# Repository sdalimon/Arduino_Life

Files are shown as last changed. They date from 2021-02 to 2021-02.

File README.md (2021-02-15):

# Arduino_Life
A little Arduino compatible LED art project

It consists of a two board stack.  
The lower board has an ATMega328 loaded with the Arduino bootloader.  It also has the row drivers for the LED array.
The upper board is an 8x8 array of LEDs in a standard row/column arrangement.

This was called Arduino Life because I planned to do Game of Life on it, but found a nicer looking pattern that doesn't need to worry about geting stuck.

The software is in the LED_Worm which implements a dot bouncing around the LEDs toggleing the current LED.  It randomly turns to give a less repeatitive pattern.  The software is written using the Arduino IDE.  

To program, use a USB to TTL (or other TTL UART) interface.  Press the reset button after clicking Program in the Arduino IDE (or install the chip in an Arduino Uno and program there).

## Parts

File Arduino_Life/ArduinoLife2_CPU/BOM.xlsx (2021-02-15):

Ref | Qnty | Value | Cmp name | Footprint | Description | Vendor
C1, C2, C3, | 3 | 100n | C | Capacitor_THT:C_Disc_D5.0mm_W2.5mm_P5.00mm | Unpolarized capacitor | RDER71H104K0P1H03B
C4, C5, | 2 | 22p | C | Capacitor_THT:C_Disc_D5.0mm_W2.5mm_P5.00mm | Unpolarized capacitor | RDE5C2A220J0S1H03A
C6, | 1 | 10u | CP1 | Capacitor_THT:CP_Radial_D6.3mm_P2.50mm | Polarised capacitor | 860130673001
J1, | 1 | Conn_01x09 | Conn_01x09 | Connector_PinSocket_2.54mm:PinSocket_1x09_P2.54mm_Vertical | Generic connector, single row, 01x09, script generated (kicad-library-utils/schlib/autogen/connector/) | PPPC091LFBN-RC
J2, J3, J4, | 3 | Conn_01x08 | Conn_01x08 | Connector_PinSocket_2.54mm:PinSocket_1x08_P2.54mm_Vertical | Generic connector, single row, 01x08, script generated (kicad-library-utils/schlib/autogen/connector/) | PPPC081LFBN-RC
J5, | 1 | Conn_01x03 | Conn_01x03 | Connector_PinHeader_2.54mm:PinHeader_1x03_P2.54mm_Horizontal | Generic connector, single row, 01x03, script generated (kicad-library-utils/schlib/autogen/connector/) | PH1RB-03-UA
J6, | 1 | KUSBX-SL-CS1N14-B | KUSBX-SL-CS1N14-B | ArduinoLife2 - CPU:KUSBX-SL-CS1N14-B |  | KUSBX-SL-CS1N14-B
Q1, Q2, Q3, Q4, Q5, Q6, Q7, Q8, | 8 | 2N3904 | 2N3904 | Package_TO_SOT_THT:TO-92_Inline | 0.2A Ic, 40V Vce, Small Signal NPN Transistor, TO-92 | 2N3904BU
R1, R2, R3, R4, R5, R6, R7, R8, R9, R10, R11, R12, R13, R14, R15, R16, | 16 | 560 | R | Resistor_THT:R_Axial_DIN0207_L6.3mm_D2.5mm_P10.16mm_Horizontal | Resistor | CF14JT560R
R17, R18, | 2 | 5k1 | R | Resistor_THT:R_Axial_DIN0207_L6.3mm_D2.5mm_P10.16mm_Horizontal | Resistor | RNMF14FTC5K10
R20, | 1 | 10k | R | Resistor_THT:R_Axial_DIN0207_L6.3mm_D2.5mm_P10.16mm_Horizontal | Resistor | CF14JT10K0
SW1, | 1 | SW_Push | SW_Push | Button_Switch_THT:SW_PUSH_6mm | Push button switch, generic, two pins | 1825910-6
U1, | 1 | ATmega328P-PU | ATmega328P-PU | Package_DIP:DIP-28_W7.62mm | PDIP28 Narrow, 32k Flash, 2kB SRAM, 1kB EEPROM | ATMEGA328P-PU
Y1, | 1 | 16M | Crystal | Crystal:HC-46X | Two pin crystal | ECS-160-20-46X
D1, D2, D3, D4, D5, D6, D7, D8, D9, D10, D11, D12, D13, D14, D15, D16, D17, D18, D19, D20, D21, D22, D23, D24, D25, D26, D27, D28, D29, D30, D31, D32, D33, D34, D35, D36, D37, D38, D39, D40, D41, D42, D43, D44, D45, D46, D47, D48, D49, D50, D51, D52, D53, D54, D55, D56, D57, D58, D59, D60, D61, D62, D63, D64, | 64 | LED | LED | LED_THT:LED_D5.0mm | LED generic | 151051RS11000
J1, | 1 | Conn_01x09 | Conn_01x09 | Connector_PinHeader_2.54mm:PinHeader_1x09_P2.54mm_Vertical | Generic connector, single row, 01x09, script generated (kicad-library-utils/schlib/autogen/connector/) | PRPC009SAAN-RC
J2, J3, J4, | 3 | Conn_01x08 | Conn_01x08 | Connector_PinHeader_2.54mm:PinHeader_1x08_P2.54mm_Vertical | Generic connector, single row, 01x08, script generated (kicad-library-utils/schlib/autogen/connector/) | PH1-08-UA

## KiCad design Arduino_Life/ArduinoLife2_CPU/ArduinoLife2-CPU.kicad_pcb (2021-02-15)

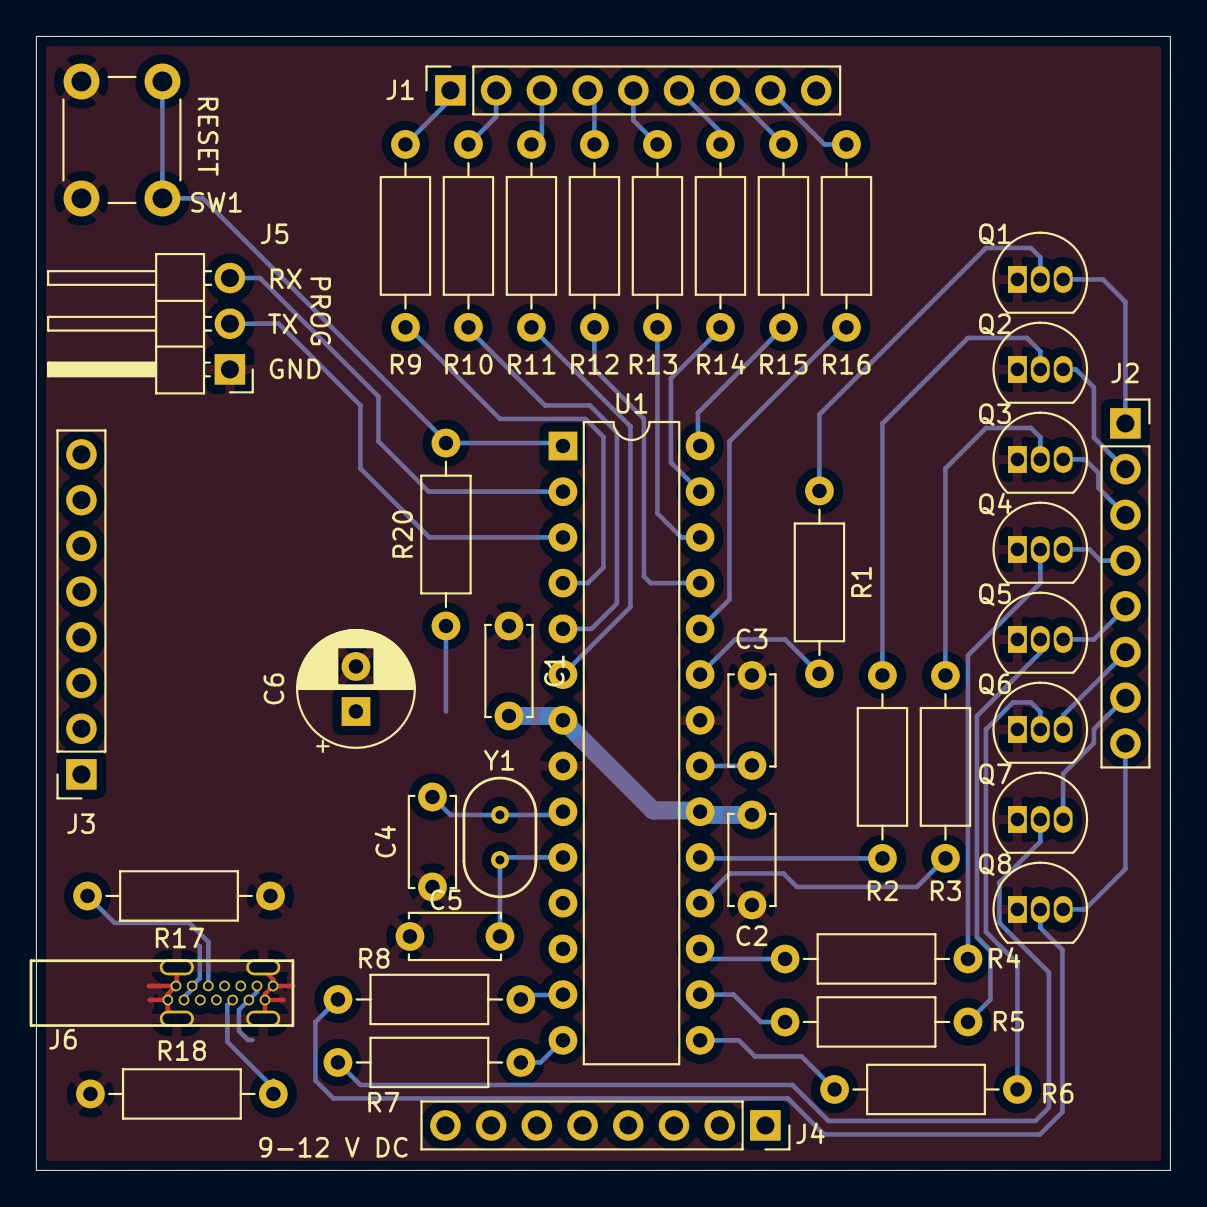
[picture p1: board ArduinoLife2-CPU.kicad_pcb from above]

Board: 2 copper layers, 63.0 x 63.0 mm, 42 parts (0 on the bottom side), 50 nets.

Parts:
C1, C2, C3: 100n; C_Disc_D5.0mm_W2.5mm_P5.00mm
C4, C5: 22p; C_Disc_D5.0mm_W2.5mm_P5.00mm
C6: 10u; CP_Radial_D6.3mm_P2.50mm
J1: Conn_01x09; PinSocket_1x09_P2.54mm_Vertical
J2, J3, J4: Conn_01x08; PinSocket_1x08_P2.54mm_Vertical
J5: Conn_01x03; PinHeader_1x03_P2.54mm_Horizontal
J6: KUSBX-SL-CS1N14-B
Q1, Q2, Q3, Q4, Q5, Q6, Q7, Q8: 2N3904; TO-92_Inline
R1, R2, R3, R4, R5, R6, R7, R8, R9, R10, R11, R12, R13, R14, R15, R16: 560; R_Axial_DIN0207_L6.3mm_D2.5mm_P10.16mm_Horizontal
R17, R18: 5k1; R_Axial_DIN0207_L6.3mm_D2.5mm_P10.16mm_Horizontal
R20: 10k; R_Axial_DIN0207_L6.3mm_D2.5mm_P10.16mm_Horizontal
SW1: SW_Push; SW_PUSH_6mm
U1: ATmega328P-PU; DIP-28_W7.62mm
Y1: 16M; HC-46X

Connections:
/C0: J1.1, R9.1
/C1: J1.2, R10.1
/C2: J1.3, R11.1
/C3: J1.4, R12.1
/C4: J1.5, R13.1
/C5: J1.6, R14.1
/C6: J1.7, R15.1
/C7: J1.8, R16.1
/CC1: J6.A5, R17.2
/CC2: J6.B5, R18.2
/R0: J2.1, Q1.3
/R1: J2.2, Q2.3
/R2: J2.3, Q3.3
/R3: J2.4, Q4.3
/R4: J2.5, Q5.3
/R5: J2.6, Q6.3
/R6: J2.7, Q7.3
/R7: J2.8, Q8.3
/RX: J5.3, U1.2
/TX: J5.2, U1.3
/UC_C0: R9.2, U1.4
/UC_C1: R10.2, U1.5
/UC_C2: R11.2, U1.6
/UC_C3: R12.2, U1.25
/UC_C4: R13.2, U1.26
/UC_C5: R14.2, U1.27
/UC_C6: R15.2, U1.28
/UC_C7: R16.2, U1.24
/UC_R0: R1.2, U1.23
/UC_R1: R2.2, U1.19
/UC_R2: R3.2, U1.18
/UC_R3: R4.2, U1.17
/UC_R4: R5.2, U1.16
/UC_R5: R6.2, U1.15
/UC_R6: R7.2, U1.14
/UC_R7: R8.2, U1.13
/X1: C4.2, U1.9, Y1.1
/X2: C5.2, U1.10, Y1.2
/~RESET: R20.2, SW1.1, U1.1
GND: C1.1, C2.1, C3.1, C4.1, C5.1, C6.2, J5.1, J6.A1, J6.A12, J6.B1, J6.B12, J6.CASE, Q1.1, Q2.1, Q3.1, Q4.1, Q5.1, Q6.1, Q7.1, Q8.1, R17.1, R18.1, SW1.2, U1.8, U1.22
unnamed: C3.2, U1.21
unnamed: Q1.2, R1.1
unnamed: Q2.2, R2.1
unnamed: Q3.2, R3.1
unnamed: Q4.2, R4.1
unnamed: Q5.2, R5.1
unnamed: Q6.2, R6.1
unnamed: Q7.2, R7.1
unnamed: Q8.2, R8.1
VCC: C1.2, C2.2, C6.1, J6.A4, J6.A9, J6.B4, J6.B9, R20.1, U1.7, U1.20

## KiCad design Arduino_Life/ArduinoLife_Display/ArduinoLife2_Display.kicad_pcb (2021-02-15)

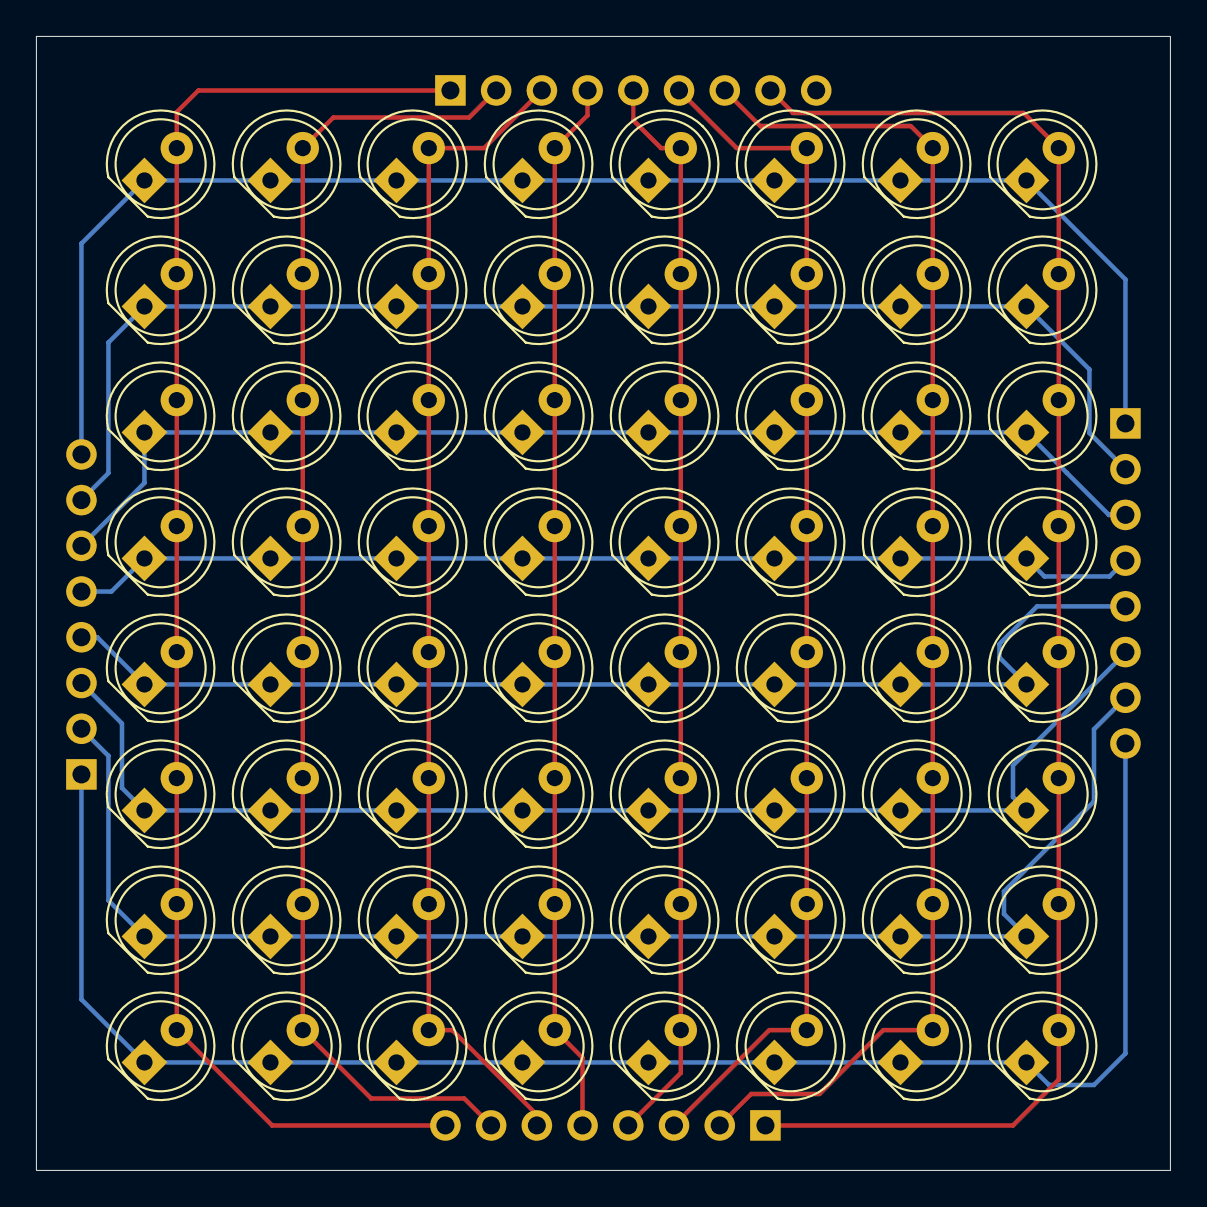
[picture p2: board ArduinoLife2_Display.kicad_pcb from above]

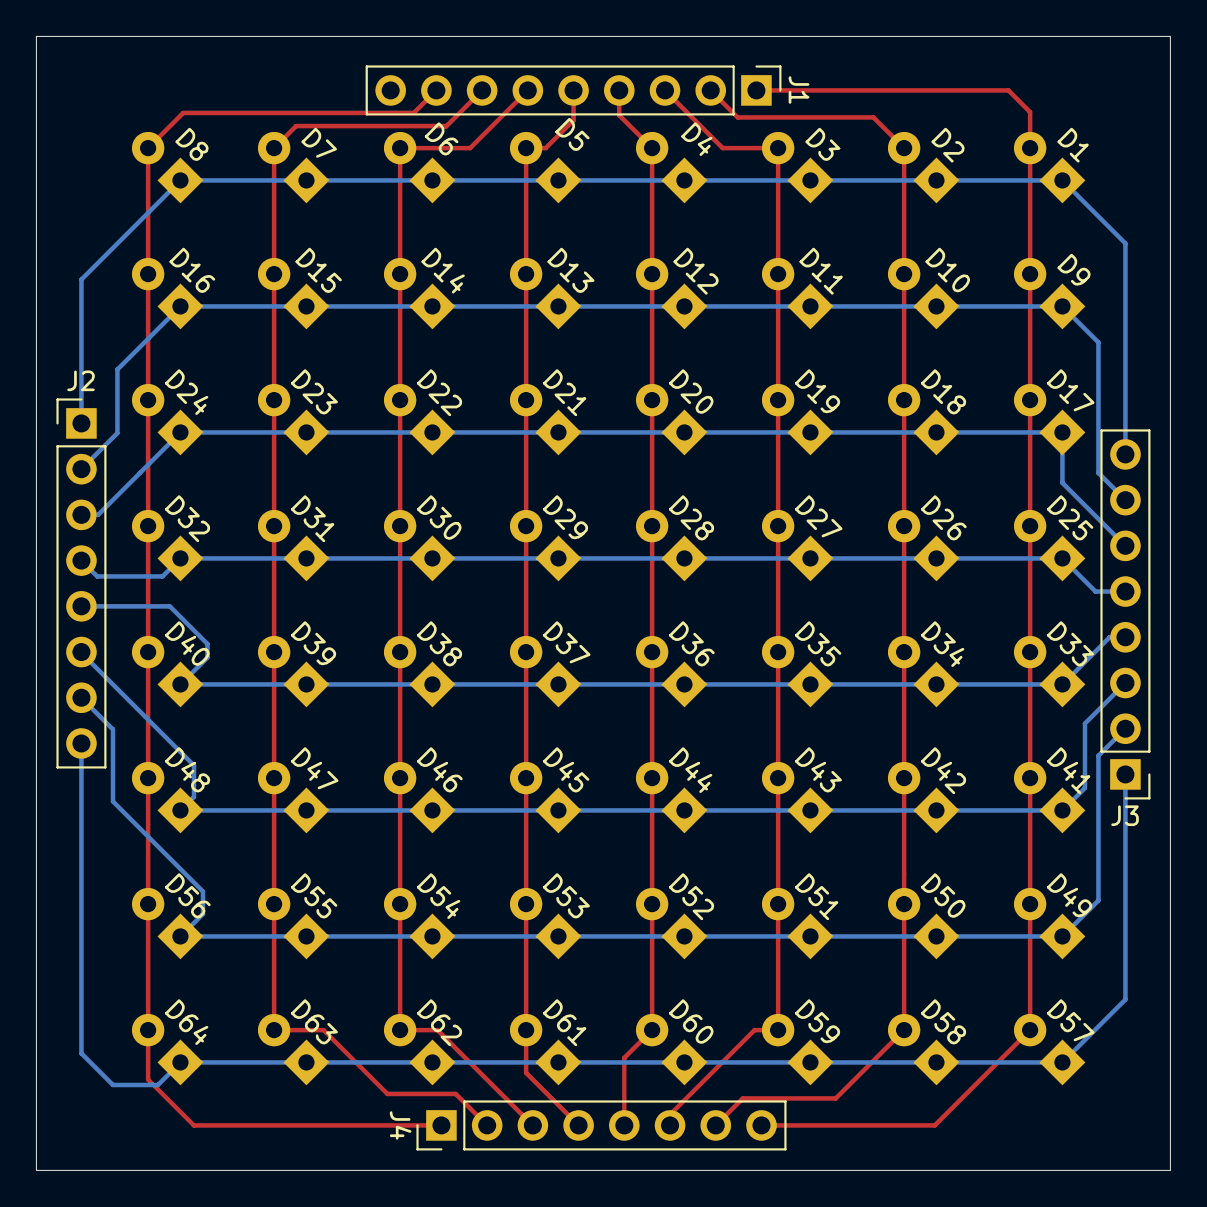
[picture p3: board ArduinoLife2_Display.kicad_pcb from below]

Board: 2 copper layers, 63.0 x 63.0 mm, 68 parts (4 on the bottom side), 16 nets.

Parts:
D1, D2, D3, D4, D5, D6, D7, D8, D9, D10, D11, D12, D13, D14, D15, D16, D17, D18, D19, D20, D21, D22, D23, D24, D25, D26, D27, D28, D29, D30, D31, D32, D33, D34, D35, D36, D37, D38, D39, D40, D41, D42, D43, D44, D45, D46, D47, D48, D49, D50, D51, D52, D53, D54, D55, D56, D57, D58, D59, D60, D61, D62, D63, D64: LED; LED_D5.0mm
J1: Conn_01x09; PinHeader_1x09_P2.54mm_Vertical
J2, J3, J4: Conn_01x08; PinHeader_1x08_P2.54mm_Vertical

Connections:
/C0: D1.2, D9.2, D17.2, D25.2, D33.2, D41.2, D49.2, D57.2, J1.1, J4.8
/C1: D2.2, D10.2, D18.2, D26.2, D34.2, D42.2, D50.2, D58.2, J1.2, J4.7
/C2: D3.2, D11.2, D19.2, D27.2, D35.2, D43.2, D51.2, D59.2, J1.3, J4.6
/C3: D4.2, D12.2, D20.2, D28.2, D36.2, D44.2, D52.2, D60.2, J1.4, J4.5
/C4: D5.2, D13.2, D21.2, D29.2, D37.2, D45.2, D53.2, D61.2, J1.5, J4.4
/C5: D6.2, D14.2, D22.2, D30.2, D38.2, D46.2, D54.2, D62.2, J1.6, J4.3
/C6: D7.2, D15.2, D23.2, D31.2, D39.2, D47.2, D55.2, D63.2, J1.7, J4.2
/C7: D8.2, D16.2, D24.2, D32.2, D40.2, D48.2, D56.2, D64.2, J1.8, J4.1
/R0: D1.1, D2.1, D3.1, D4.1, D5.1, D6.1, D7.1, D8.1, J2.1, J3.8
/R1: D9.1, D10.1, D11.1, D12.1, D13.1, D14.1, D15.1, D16.1, J2.2, J3.7
/R2: D17.1, D18.1, D19.1, D20.1, D21.1, D22.1, D23.1, D24.1, J2.3, J3.6
/R3: D25.1, D26.1, D27.1, D28.1, D29.1, D30.1, D31.1, D32.1, J2.4, J3.5
/R4: D33.1, D34.1, D35.1, D36.1, D37.1, D38.1, D39.1, D40.1, J2.5, J3.4
/R5: D41.1, D42.1, D43.1, D44.1, D45.1, D46.1, D47.1, D48.1, J2.6, J3.3
/R6: D49.1, D50.1, D51.1, D52.1, D53.1, D54.1, D55.1, D56.1, J2.7, J3.2
/R7: D57.1, D58.1, D59.1, D60.1, D61.1, D62.1, D63.1, D64.1, J2.8, J3.1

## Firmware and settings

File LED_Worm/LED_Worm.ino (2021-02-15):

// Randomly toggle LEDs on an 8x8 array

#include <MsTimer2.h>

const int PIN_ROW[8] = {A0, 13, 12, 11, 10, 9, 8, 7};
const int PIN_COL[8] = {2, 3, 4, A2, A3, A4, A5, A1};

volatile unsigned char vidmem[8];

int x;
int y;
int dx;
int dy;

void setup() {
  Serial.begin(115200);

  randomSeed(analogRead(A0));

  // Set pins to output
  for (int i = 0; i < 8; i++) {
    digitalWrite(PIN_ROW[i], LOW);
    digitalWrite(PIN_COL[i], LOW);
    pinMode(PIN_ROW[i], OUTPUT);
    pinMode(PIN_COL[i], OUTPUT);
  }

  memset(vidmem, 0, sizeof(vidmem));

  MsTimer2::set(2, scanDisp);
  MsTimer2::start();

  x = random(8);
  y = random(8);
  do {
    dx = random(3) - 1; // -1, 0 ,1
    dy = random(3) - 1; // -1, 0, 1
  } while (dx == 0 && dy == 0); // (0,0) is not allowed)
}

// Swicth to the next line of the display
void scanDisp() {
  static int y = 0;
  int x;
  digitalWrite(PIN_ROW[y], LOW);
  for (x = 0; x < 8; x++) digitalWrite(PIN_COL[x], LOW);
  y = (y + 1) % 8;
  digitalWrite(PIN_ROW[y], HIGH);
  for (x = 0; x < 8; x++) {
    digitalWrite(PIN_COL[x], (vidmem[y] & (1 << x)) ? HIGH : LOW);
  }
}



int sgn(float a) {
  if (a > 0) return 1;
  if (a < 0) return -1;
  return 0;
}

void loop() {
  int tdx, tdy;

  vidmem[y] ^= (1 << x); // Toggle current bit
  //memset(vidmem, 0, 8);
  //vidmem[y] |= (1 << x); // Toggle current bit

  x = x + dx;
  if (x == 8) {
    x = 7;
    dx = -dx;
  }
  if (x == -1) {
    x = 0;
    dx = -dx;
  }
  y = y + dy;
  if (y == 8) {
    y = 7;
    dy = -dy;
  }
  if (y == -1) {
    y = 0;
    dy = -dy;
  }

  Serial.print("X: "); Serial.print(x); Serial.print(", Y: "); Serial.println(y);

  switch (random(10)) {
    case 0: // Turn left
      tdx = sgn(dx * cos(PI / 4) - dy * sin(PI / 4));
      tdy = sgn(dx + sin(PI / 4) + dy * cos(PI / 4));
      dx = tdx;
      dy = tdy;
      break;
    case 1: // Turn Right
      tdx = sgn(dx * cos(-PI / 4) - dy * sin(-PI / 4));
      tdy = sgn(dx + sin(-PI / 4) + dy * cos(-PI / 4));
      dx = tdx;
      dy = tdy;
      break;
    default: // Do nothing
      break;
  }
  delay(250);
}
